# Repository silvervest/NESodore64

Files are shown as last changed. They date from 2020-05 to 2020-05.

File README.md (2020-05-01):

# NESodore64

NESodore64 is an AVR microcontroller board that interfaces with an original NES controller pad, and outputs signals that emulate a joystick for Commodore 64's. It might be used on other computers of the era, but I haven't tested it on any and guarantee nothing!

It's creation was documented in [this YouTube video](https://youtu.be/1u0i-EAIm1I)

## Pin details

Here's some tables describing the pins and their connections found or used as part of this project.

### NES pad

The NES pad seems to have identical wire colours, as they are specifically written on the back which colour goes where, but not which wire does what, so here's that chart for ya.

| Colour | Pin | Purpose |
|---|-----|---|
| Brown  | 1 | Ground  |
| Red | 2 | Clock |
| Orange | 3 | Latch |
| Yellow | 4 | Data |
| White  | 7 | +5V |

### C64 joystick

A LOT more detail about the port at https://www.c64-wiki.com/wiki/Control_Port.

In the joystick I used, however, these were the wire colours. Your joystick will PROBABLY have different colours, so unless you have the exact one used in my video, don't use this as a guide. Even then, just buzz the wires out yourself to be sure!

| Colour | Pin | Purpose | 
|---|-----|---|
| White  | 1 | Joy UP |
| Blue | 2 | Joy DOWN  |
| Green  | 3 | Joy LEFT  |
| Brown  | 4 | Joy RIGHT |
| Yellow | 5 | Paddle Y  |
| Orange | 6 | But FIRE  |
| Red | 7 | +5V |
| Black  | 8 | Ground |
| Grey | 9 | Paddle X  |

## Contributing
Pull requests are welcome. For major changes, please open an issue first to discuss what you would like to change.

Please make sure to update tests as appropriate.

## License
[MIT](https://choosealicense.com/licenses/mit/)

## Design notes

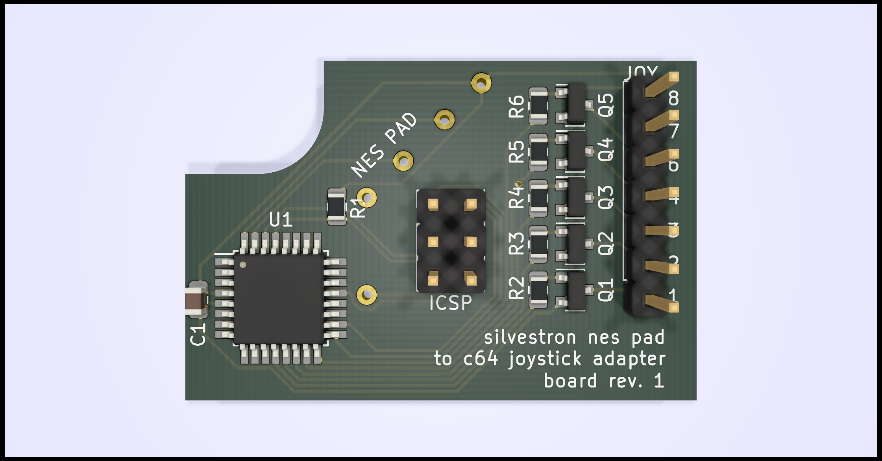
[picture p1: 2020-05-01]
render.png

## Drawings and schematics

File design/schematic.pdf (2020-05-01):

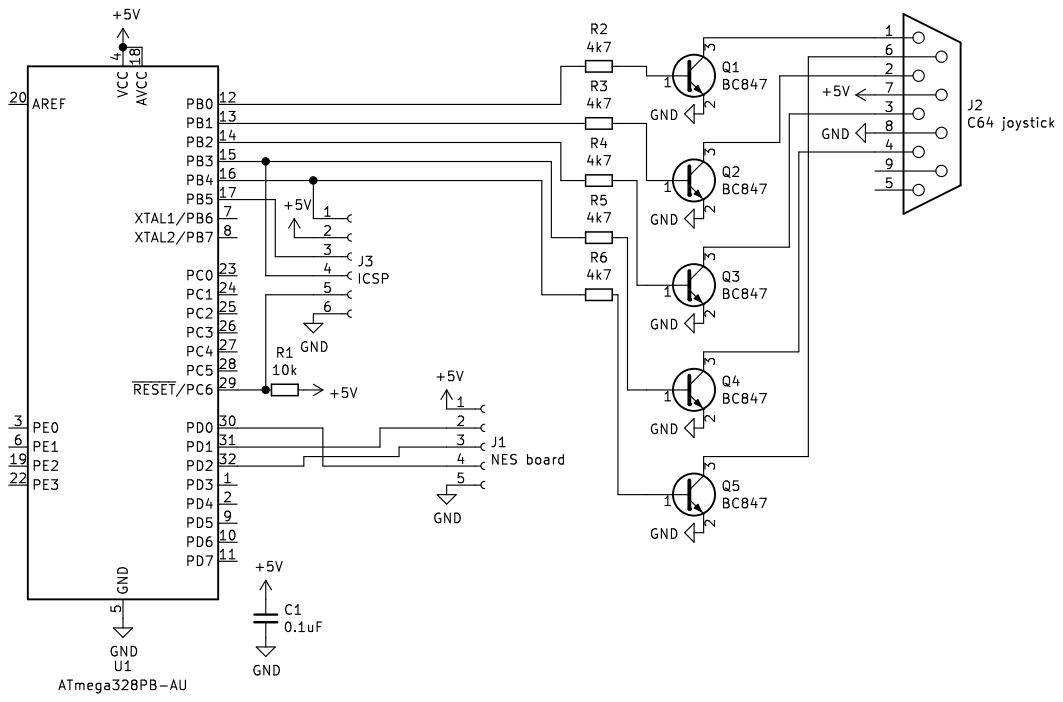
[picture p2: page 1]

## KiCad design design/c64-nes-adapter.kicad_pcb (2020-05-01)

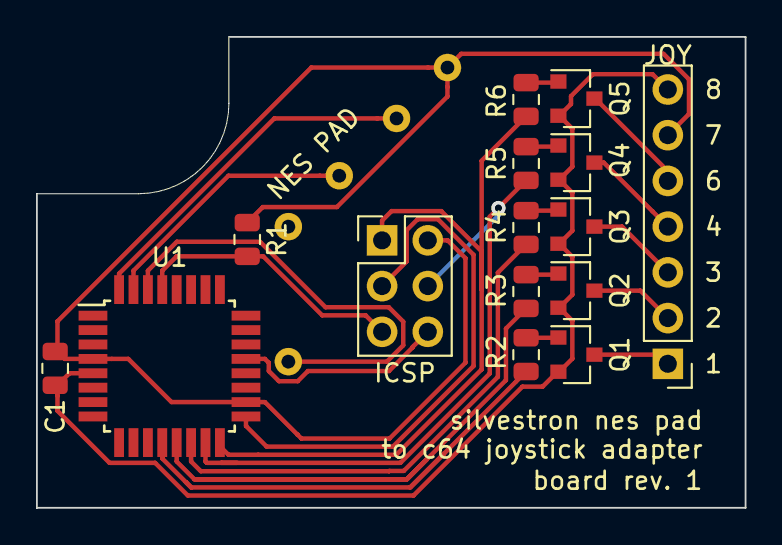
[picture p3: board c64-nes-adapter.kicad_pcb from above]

Board: 2 copper layers, 39.4 x 26.2 mm, 16 parts (0 on the bottom side), 22 nets.

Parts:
C1: 0.1uF; C_0805_2012Metric
ICSP: ICSP; PinHeader_2x03_P2.54mm_Vertical
JOY: C64 joystick; PinHeader_1x07_P2.54mm_Vertical
NES PAD: NES board; NES_Dpad_Conn
Q1, Q2, Q3, Q4, Q5: BC847; SOT-23
R1: 10k; R_0805_2012Metric
R2, R3, R4, R5, R6: 4k7; R_0805_2012Metric
U1: ATmega328PB-AU; TQFP-32_7x7mm_P0.8mm

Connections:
+5V: C1.1, ICSP.2, JOY.7, NES PAD.1, R1.1, U1.4, U1.18
GND: C1.2, ICSP.6, JOY.8, NES PAD.5, Q1.2, Q2.2, Q3.2, Q4.2, Q5.2, U1.5, U1.21
unnamed: NES PAD.2, U1.31
unnamed: NES PAD.3, U1.32
unnamed: NES PAD.4, U1.30
unnamed: JOY.1, Q1.3
unnamed: JOY.2, Q2.3
unnamed: JOY.3, Q3.3
unnamed: JOY.4, Q4.3
unnamed: JOY.6, Q5.3
unnamed: ICSP.1, R6.2, U1.16
unnamed: ICSP.3, U1.17
unnamed: ICSP.4, R5.2, U1.15
unnamed: ICSP.5, R1.2, U1.29
unnamed: Q1.1, R2.1
unnamed: Q2.1, R3.1
unnamed: Q3.1, R4.1
unnamed: Q4.1, R5.1
unnamed: Q5.1, R6.1
unnamed: R2.2, U1.12
unnamed: R3.2, U1.13
unnamed: R4.2, U1.14

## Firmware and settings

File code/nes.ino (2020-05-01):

// Pins to connect to NES controller
#define NES_CLK   1 // PD2
#define NES_LATCH 2 // PD1
#define NES_DATA  0 // PD0

// bit positions of the data byte read from controller
#define NES_A      0b10000000
#define NES_B      0b01000000
#define NES_SELECT 0b00100000
#define NES_START  0b00010000
#define NES_UP     0b00001000
#define NES_DOWN   0b00000100
#define NES_LEFT   0b00000010
#define NES_RIGHT  0b00000001

// output pins for the joystick port
#define JOY_PIN_UP     8  // PB0
#define JOY_PIN_DOWN   9  // PB1
#define JOY_PIN_LEFT   10 // PB2
#define JOY_PIN_RIGHT  11 // PB3
#define JOY_PIN_FIRE   12 // PB4

// bit positions for the joystick pins
#define JOY_UP    0b00010000
#define JOY_DOWN  0b00001000
#define JOY_LEFT  0b00000100
#define JOY_RIGHT 0b00000010
#define JOY_FIRE  0b00000001

// mode set masks
#define MODE_NORMAL     0b11011111 // SELECT - dpad is normal, B is jump, A is fire
#define MODE_RAPIDFIRE  0b10011111 // SELECT + B - dpad is normal, B is jump, hold A for rapid fire
#define MODE_WADDLE     0b01011111 // SELECT + A - dpad is normal, B is waddle, A is fire - hold right and B to waddle faster

// hold our current controller state
byte controllerState = 255; // initial state of 255 means no buttons pressed
byte lastControllerState = 255; // hold the previous state of the controller also
byte joystickState = 0; // initial state of 0 means no buttons pressed
byte currentMode = MODE_NORMAL; // might as well use the mask to store this too!
bool modeSelect = false;

// some mode specific variables for tracking
byte waddleState = 0; // 0 = left, 1 = right - always start with a left stroke
int waddleCount = 0;
unsigned long lastWaddleTime = 0;
byte fireState = LOW;
unsigned long lastFireTime = 0;

// modes have three speeds, in low medium high speed order
int waddleSpeeds[3] = {20, 50, 100}; // in milliseconds!
int fireSpeeds[3] = {20, 50, 100}; // in milliseconds!

void setup() {
  // set up our clock and latch pins for output, ensuring they begin low
  digitalWrite(NES_CLK, LOW);
  pinMode(NES_CLK, OUTPUT);
  digitalWrite(NES_LATCH, LOW);
  pinMode(NES_LATCH, OUTPUT);

  // our data pin for input
  pinMode(NES_DATA, INPUT);

  // and the joystick ports for output
  digitalWrite(JOY_UP, LOW);
  pinMode(JOY_PIN_UP, OUTPUT);
  digitalWrite(JOY_DOWN, LOW);
  pinMode(JOY_PIN_DOWN, OUTPUT);
  digitalWrite(JOY_LEFT, LOW);
  pinMode(JOY_PIN_LEFT, OUTPUT);
  digitalWrite(JOY_RIGHT, LOW);
  pinMode(JOY_PIN_RIGHT, OUTPUT);
  digitalWrite(JOY_FIRE, LOW);
  pinMode(JOY_PIN_FIRE, OUTPUT);

  // make sure you disable serial communication, as we are re-using the TX and RX pins
  // Serial.begin(115200);
}

void loop() {
  // for timing at the end of this loop
  unsigned long start = micros();

  // get the controller state!
  readControllerState();
  if (lastControllerState != controllerState)
    Serial.println(controllerState, BIN);

  // while SELECT is held, we will move into mode select
  // as soon as SELECT is let go of, the mode will be set
  if (checkButtonState(NES_SELECT)) {
    // make sure we're not outputting anything on the joystick
    joystickState = 0;
    setJoystickPins();
    
    // loop until SELECT is let go of
    Serial.println("entering select mode");
    // starting off, put us into mode select and set the mode to NORMAL
    modeSelect = true;
    currentMode = MODE_NORMAL;
    while (true) {

      // wait a full cycle and read the state again
      delayMicroseconds(16666);
      readControllerState();

      // only set the mode if it's known and we're in mode select
      if (modeSelect == true && controllerState == MODE_RAPIDFIRE || controllerState == MODE_WADDLE) {
        currentMode = controllerState;
        if (lastControllerState != controllerState) {
          Serial.print("setting mode ");
          Serial.println(currentMode, BIN);
        }

        // now that we've picked a mode, lock it in until SELECT is let go of
        modeSelect = false;
      }

      // SELECT was let go of, so return to our regular programming
      if (checkButtonState(NES_SELECT) == false) {
        Serial.println("exiting select mode");
        return; // just exit this loop back to 
      }
    }
  } else { // normal mode, just handle the buttons!
    setJoystickPins();
  }

  // try to loop at 60Hz, every 16666 microsec
  // we can no doubt go much faster than this, but the NES polls normally at 60Hz so let's stick to that
  unsigned long diff = 16666 - (micros() - start);
  if (diff < 16666 && diff > 0)
    delayMicroseconds(diff);
}

byte readControllerState() {
  // pulse the latch to ask the controller to lock in current button state
  digitalWrite(NES_LATCH, HIGH);
  digitalWrite(NES_LATCH, LOW);

  lastControllerState = controllerState;

  // read a byte of data from the controller
  // first read is the first button, ready to roll
  controllerState = digitalRead(NES_DATA);

  // then loop over the remaining 7 bits, shifting the last bit left each time
  for (int i = 1; i <= 7; i ++) {
    digitalWrite(NES_CLK, HIGH);
    controllerState = controllerState << 1;
    controllerState = controllerState + digitalRead(NES_DATA);
    digitalWrite(NES_CLK, LOW);
  }

  // controller unplugged!
  if (controllerState == 0) {
    controllerState = 255;
  }

  // delay a bit for debounce
  delayMicroseconds(5000);
  
  return controllerState;
}

// compare the current controller 
bool checkButtonState(byte button) {
  return (bool)!(button & controllerState);
}

void setJoystickPins() {
  // B button on the NES pad emulates an UP press on the joystick in normal mode
  if (checkButtonState(NES_UP) || (currentMode == MODE_NORMAL && checkButtonState(NES_B))) {
    digitalWrite(JOY_PIN_UP, HIGH);
  } else {
    digitalWrite(JOY_PIN_UP, LOW);
  }

  if (checkButtonState(NES_DOWN)) {
    digitalWrite(JOY_PIN_DOWN, HIGH);
  } else {
    digitalWrite(JOY_PIN_DOWN, LOW);
  }

  if (checkButtonState(NES_LEFT)) {
    digitalWrite(JOY_PIN_LEFT, HIGH);
  } else {
    digitalWrite(JOY_PIN_LEFT, LOW);
  }

  if (checkButtonState(NES_RIGHT)) {
    digitalWrite(JOY_PIN_RIGHT, HIGH);
  } else {
    digitalWrite(JOY_PIN_RIGHT, LOW);
  }

  // B button on the NES pad is also fire in rapid fire mode
  if (checkButtonState(NES_A) || (currentMode == MODE_RAPIDFIRE && checkButtonState(NES_B))) {
    if (currentMode == MODE_RAPIDFIRE) {
      // pick a rapid fire duration based on buttons held
      // A alone is 100ms
      // B alone is 50ms
      // A+B is 20ms
      int delayDuration = fireSpeeds[2];
      if (checkButtonState(NES_A) && checkButtonState(NES_B)) {
        delayDuration = fireSpeeds[0];
      } else if (checkButtonState(NES_B)) {
        delayDuration = fireSpeeds[1];
      }

      // determine whether we should toggle fire based on delay duration
      unsigned long currentTime = millis();
      if ((currentTime - lastFireTime) > delayDuration) {
        lastFireTime = currentTime;

        fireState = !fireState;
      }

      // do it
      digitalWrite(JOY_PIN_FIRE, fireState);
    } else {
      // normal mode, just hold fire high
      digitalWrite(JOY_PIN_FIRE, HIGH);
    }
  } else {
    digitalWrite(JOY_PIN_FIRE, LOW);
    fireState = LOW;
  }

  // in waddle mode, B emulates the back-and-forth left/right directions needed in sports games
  if (currentMode == MODE_WADDLE && checkButtonState(NES_B)) {
    // holding right while holding B will increase the waddle speed, and holding left will waggle slower for some reason
    int delayDuration = waddleSpeeds[1];
    if (checkButtonState(NES_RIGHT)) {
      delayDuration = waddleSpeeds[0];
    } else if (checkButtonState(NES_LEFT)) {
      delayDuration = waddleSpeeds[2];
    }

    // determine whether we should toggle the waddle based on delay duration and our position in the waddle
    unsigned long currentTime = millis();
    if ((currentTime - lastWaddleTime) > delayDuration) {
      lastWaddleTime = currentTime;

      waddleState = !waddleState;
    }

    digitalWrite(JOY_PIN_LEFT, waddleState);
    digitalWrite(JOY_PIN_RIGHT, !waddleState);
  } else {
    waddleState = 0;
  }

}
